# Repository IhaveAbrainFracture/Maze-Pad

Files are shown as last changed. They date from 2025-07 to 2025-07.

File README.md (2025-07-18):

# Maze-Pad made by @TheVirtuoso on slack, Vikas IRL
A general spin on a macro-pad, with a fully customised case, PCB, and Firmware. It should also be fully assemblable and useable less than 20 mins after getting everything. Big thanks to Hack Club (Highway) and PCBway for helping me make this





Here is the full cad model to view before you download anything or want a deeper look
https://cad.onshape.com/documents/6287fe38e10122eb28751222/w/de1210ab97eae6cc3d55f10b/e/6d662cd5a03a31552cd37cf9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

# sob story/ why im making this
im a broke highschool student while simultaniously being the youngest in my family often what this mean is all  (if not most) of the technology i own is either a hand-me-down, something i bought myself or something i 'borrowed without the intention of returning' to prove this point want to guess what my current keyboard and mouse look like? Wrong its one of those chunky school keyboard and mice combos that your school bulk buys for there comp room. aside i rly needed an upgrade so i decide to stop being a lazy and work on something. further down the line i also plan on making a keyboard so i kind of treated this as a 'test' run so i could learn the ropes and all

# Specification /cool gimicks (software)
- fully custom code (ie i didnt just yoink the hackpad guide code and make some tweaks)
- 4 macros ( Copy,Paste,Save and alt tab)
- 2 light control buttons ( change in colour, change in pattern)
- 1 layer (I plan on making this 2 layer or more in the future)

 # Specification /cool gimicks (Electronics)
  - wired in a 2x3 matrix
  - custom pcb with funni silk image
  - 2 leds (Neo pixels) which are poorly spaced apart
  - Hopefully smd mounted Xiao
  - diodes at the back
  - 

# Specification /cool gimicks (Mechanical)
- fully custom case which doesnt require screws, Bolts or glue (i designed the case based on cool woodworking stuff)
- 7 fully custom mazes for your ADHD
- Custom Maze themed keycaps



- Groves on the side
- maximum fillets
- high mounted cover (this is on purpose i swear, its so it fits my stuff)
- crude hole to look over your enslaved xiao
- backlighting
- funni logos and names
- its black, and white
 

# instruction to build
ngl if ur building this ur either chonicaly lazy or are collecting hackpads liek infinity stones cos like it cannot be that hard to build your ow. *Aside*
1. plug in your xiao and hold the boot button (clickty clackity on the right) then move the entire firmware folder into the xiao
2. assemble the easy stuff ie the keycaps and put them of the switches
3. place the pcb and all soldered part attacked to it into the main bases (the chunky 3D print)
5. in the allocated slot add the side connector thing thats white and the other white part, for the small bridge if u want the random logoing i put use that side if not rotate it 180 and place it
6. place the case lid and test
7. place small bearing balls into all the mazes
8. done

# bill of mats

| Item | Ammount |From where|
| --- | --- |---|
|  mx switches x6  |  |from hackpad kit (i need one of the kits btw)|
|Seeed XIAO RP2040 x1 ||("")|
|SK6812 MINI-E LEDs x2 ||("")|
|3D Printing| none|Printing legion|
|PCB|??$|PCBWAY, Im getting sponsered :D < |
|Solder Iron|??|???|
|Flux|$1.53|"https://www.aliexpress.com/item/1005008783332875.html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"order"%3A"231"%2C"eval"%3A"1"%7D&pdp_npi=4%40dis%21AUD%217.41%211.53%21%21%2134.52%217.16%21%40212e508d17522305550312149ef5c6%2112000046648707772%21sea%21AU%210%21ABX&curPageLogUid=8c35HYaTwcCc&utparam-url=scene%3Asearch%7Cquery_from%3A"|
|Solder|$1.53| https://www.aliexpress.com/item/1005007703287757.html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"order"%3A"3030"%2C"eval"%3A"1"%7D&pdp_npi=4%40dis%21AUD%216.45%211.53%21%21%2130.03%217.13%21%400b1bf20817522311015765496e776c%2112000041915671265%21sea%21AU%210%21ABX&curPageLogUid=g3sCp5CWQzIl&utparam-url=scene%3Asearch%7Cquery_from%3A|

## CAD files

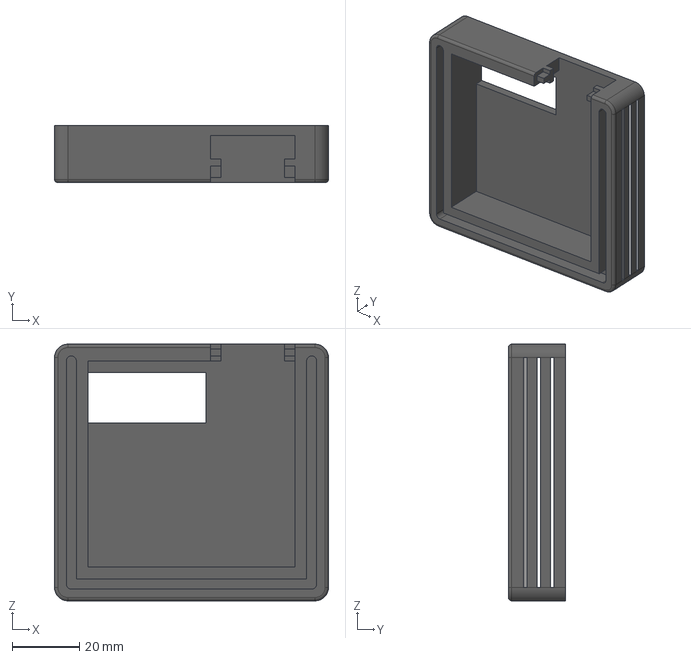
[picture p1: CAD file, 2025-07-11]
CASE FILES./All 3D printed stuff - Main base.step
81.4 x 17.0 x 76.2 mm

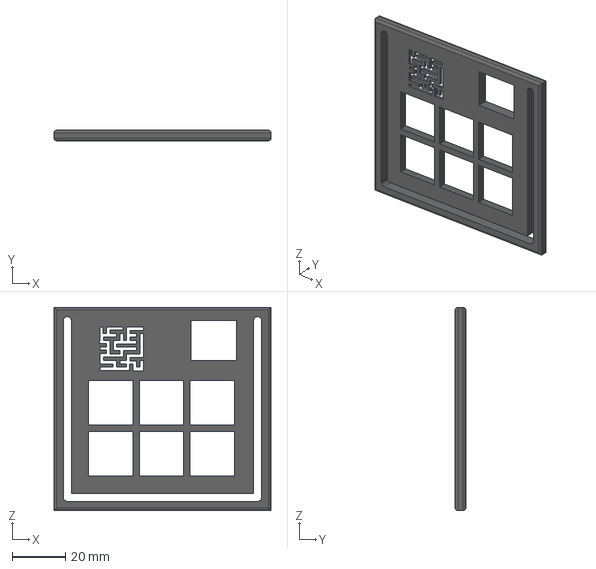
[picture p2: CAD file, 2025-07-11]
CASE FILES./All 3D printed stuff - Case.step
81.4 x 4.00 x 76.2 mm

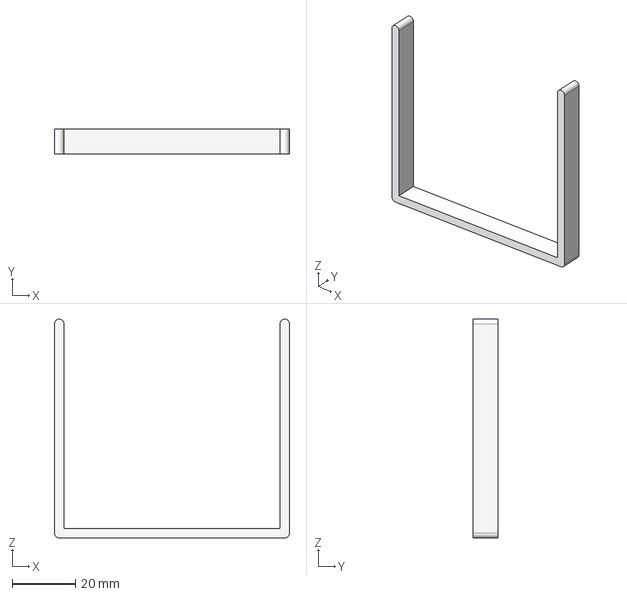
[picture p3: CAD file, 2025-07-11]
CASE FILES./All 3D printed stuff - Side Connecter.step
74.4 x 8.00 x 69.2 mm

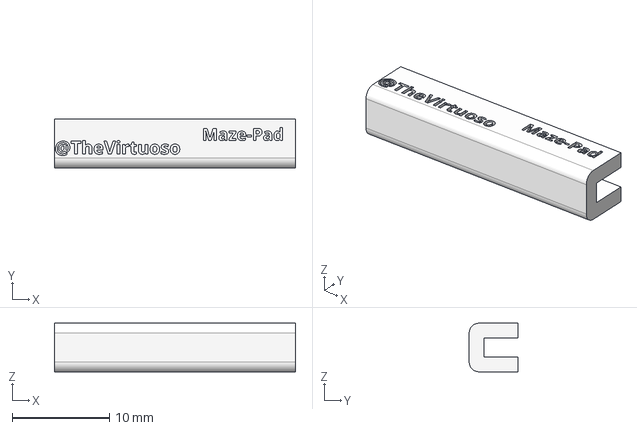
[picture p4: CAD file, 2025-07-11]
CASE FILES./All 3D printed stuff - Front Bridge.step
24.8 x 5.00 x 5.00 mm

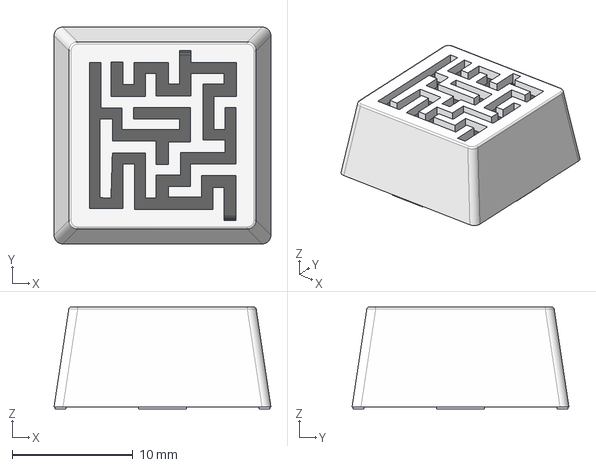
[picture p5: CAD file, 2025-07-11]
CASE FILES./Keycap.step
18.0 x 18.0 x 8.45 mm

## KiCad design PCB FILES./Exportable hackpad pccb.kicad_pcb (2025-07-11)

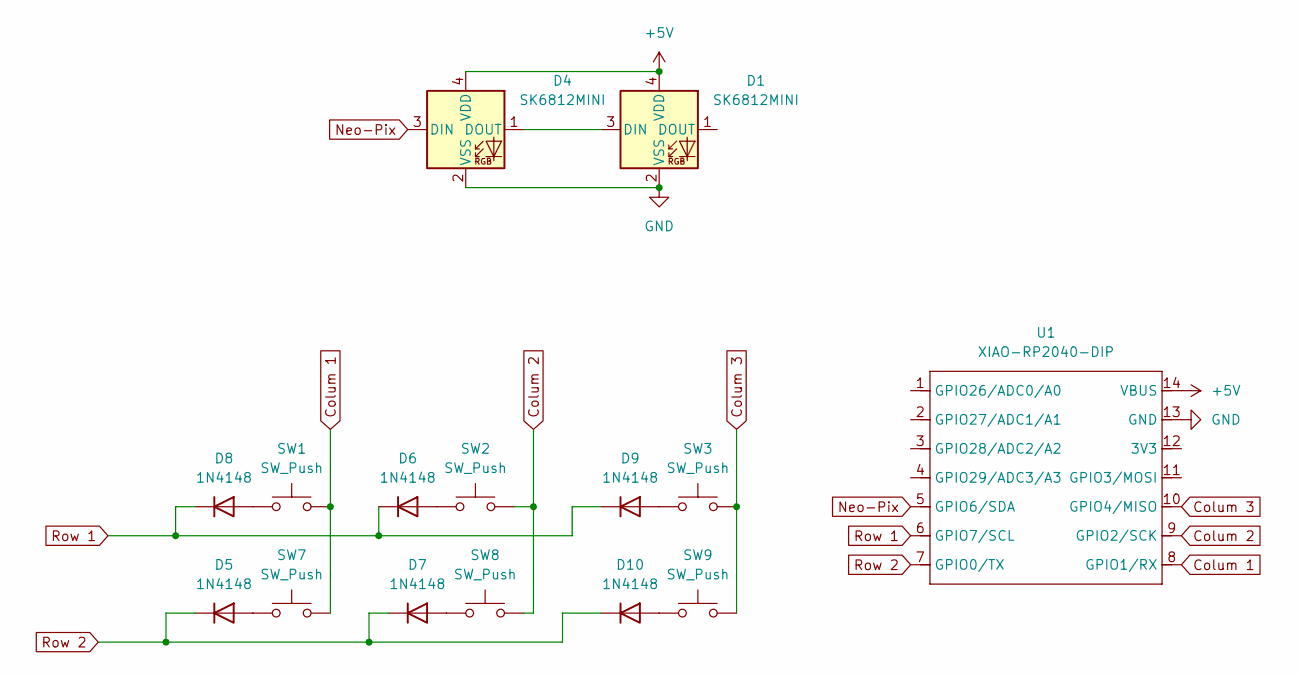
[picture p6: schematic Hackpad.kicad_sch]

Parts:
D1, D4: SK6812MINI; LED_SK6812MINI_PLCC4_3.5x3.5mm_P1.75mm
D5, D6, D7, D8, D9, D10: 1N4148; D_DO-35_SOD27_P7.62mm_Horizontal
SW1, SW2, SW3, SW7, SW8, SW9: SW_Push; SW_Cherry_MX_1.00u_PCB
U1: XIAO-RP2040-DIP

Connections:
+5V: D1.4 (VDD), D4.4 (VDD), U1.14 (VBUS)
Colum 1: SW1.2, SW7.2, U1.8 (GPIO1/RX)
Colum 2: SW2.2, SW8.2, U1.9 (GPIO2/SCK)
Colum 3: SW3.2, SW9.2, U1.10 (GPIO4/MISO)
GND: D1.2 (VSS), D4.2 (VSS), U1.13 (GND)
Neo-Pix: D4.3 (DIN), U1.5 (GPIO6/SDA)
unnamed: D1.3 (DIN), D4.1 (DOUT)
unnamed: D5.2 (A), SW7.1
unnamed: D6.2 (A), SW2.1
unnamed: D7.2 (A), SW8.1
unnamed: D8.2 (A), SW1.1
unnamed: D9.2 (A), SW3.1
unnamed: D10.2 (A), SW9.1
Row 1: D6.1 (K), D8.1 (K), D9.1 (K), U1.6 (GPIO7/SCL)
Row 2: D5.1 (K), D7.1 (K), D10.1 (K), U1.7 (GPIO0/TX)

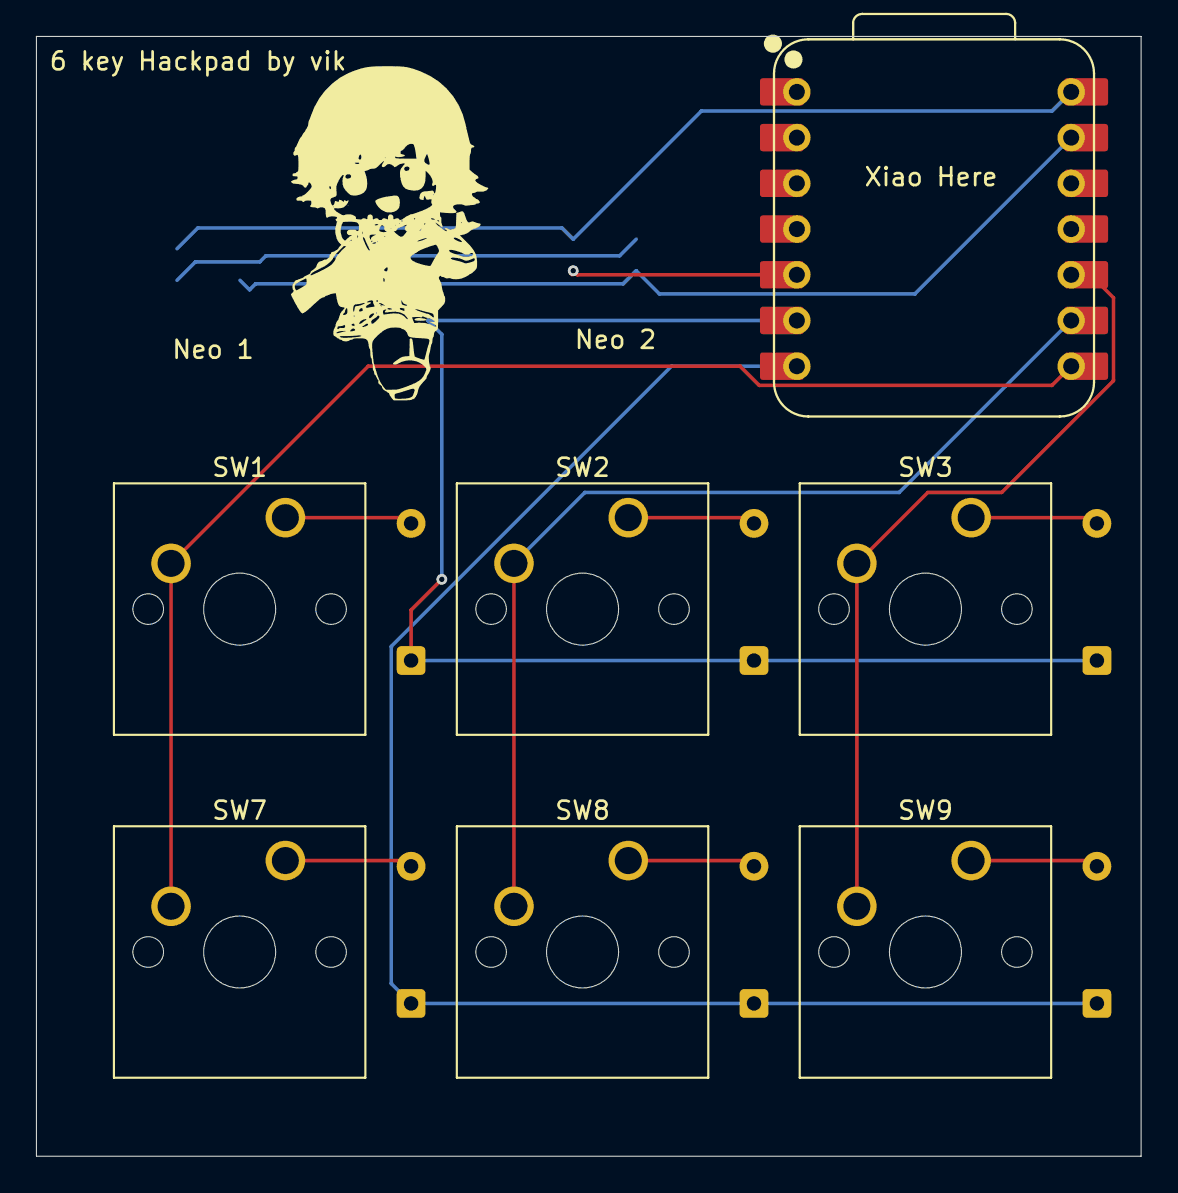
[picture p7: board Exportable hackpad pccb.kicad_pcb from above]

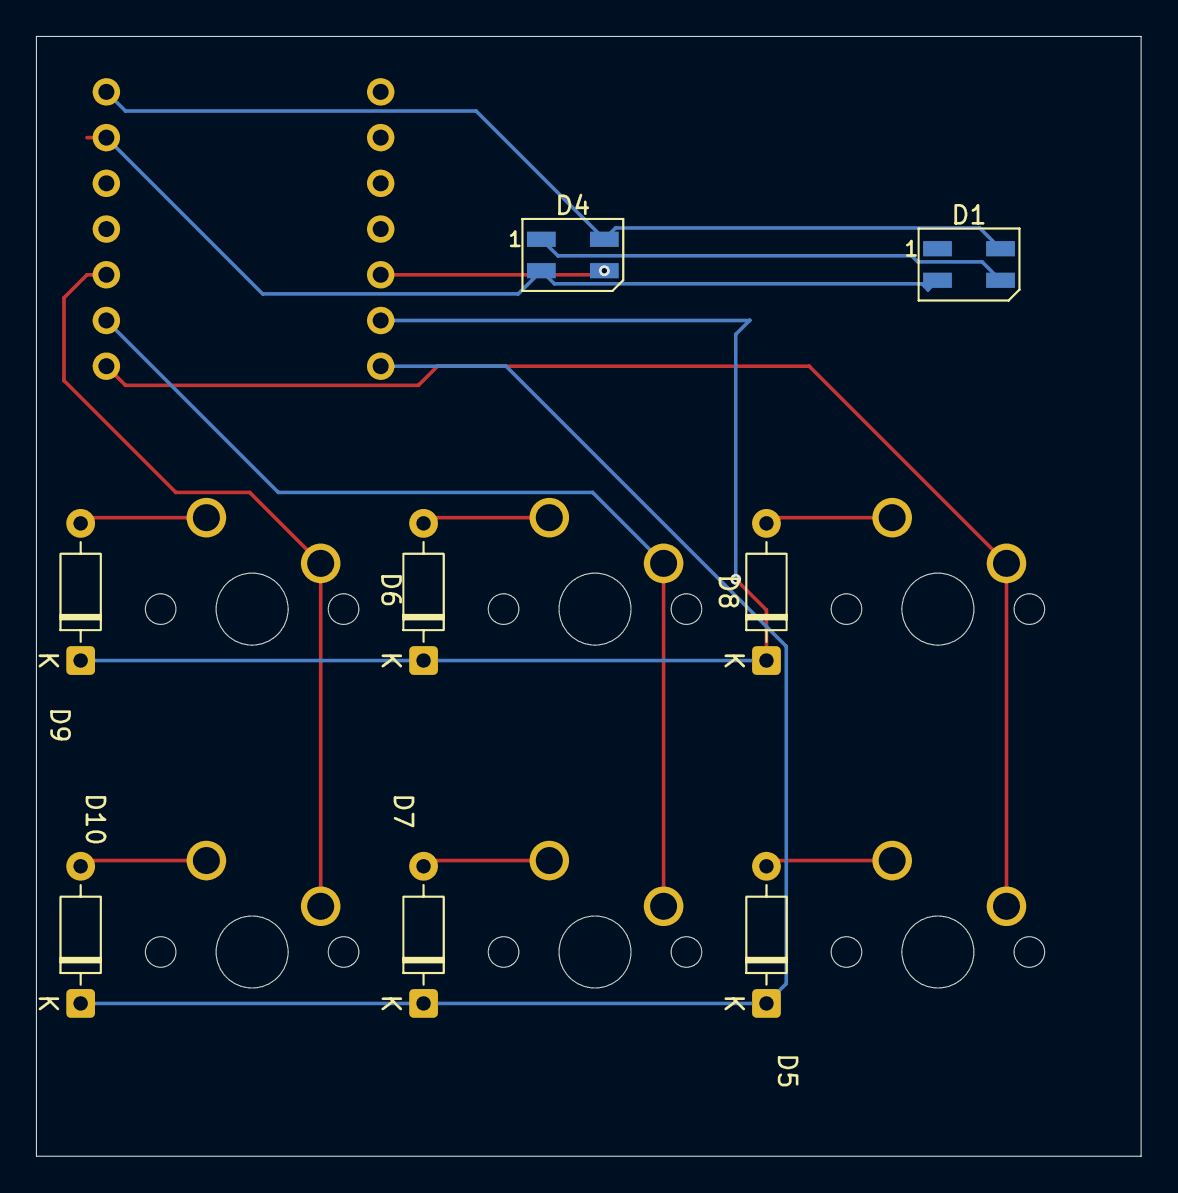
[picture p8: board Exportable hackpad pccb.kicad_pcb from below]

Board: 2 copper layers, 61.4 x 62.2 mm, 15 parts (8 on the bottom side), 15 nets.

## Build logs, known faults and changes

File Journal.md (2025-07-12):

---
title: "Maze-Pad"
author: "TheVirtuoso (me)"
description: "A maze themed hackpad/macropad"
created_at: "09/07/25"
---

just a brief heads up that i did not journal in real time for this meaning thatwriting everything in past tense/ from memory

Total hours ~17

# 9/07/25 ~5h hours 
the plan is to work on electronics. already had a look at the hackpad guide  and had a long discussion with taran(hackpad nerd) and he suggested i start with a pcb so thats what im doing. also as a note it was rly cool to learn how to finnaly make pcbs

so this was my first attempt at a matrix and i mean its obvious to me now how cooked it was but again learning exp on that note here is my 2nd attempt after bothering taran

then finnaly after watching like 3 yt videos and stuff i got this it should also be noted that i cut down on the amount of neo pixels cos yes 


so like making the schematics should be the easy part right? WRONG IM STUPID. in short i took 3 attempt at wiring my stuff here are the attempts





and guess the funny thing the text i added was in edge cut and i had no clue untill 2h later so im here panicking and stressing and all i had to do was click clack either way the final pcb and schematics look like this




# 10/07/25 ~8h
i think i finished pcb and just collapsed cos i was sendign msgs at 2 am and then poof so ye. either way im quite confident in my cad skills so i expected this to not make long. damn i was wrong im gonna pop some picture here and then explain stuff









aight time to explain, so the first image is the major sketch which provides extrudes for the case lid,base and side connector. more or less this is the big thing that everythign is based on. the following images are of me importing the pcb,switches and xiaos while assemblying them, as a note in onshape u have a area to make parts and a area to assemble parts so if you import a pcb with a xiao on it guess what you gotta make that xiao then mate it to the pcb its like being given a bag of legos without instructions. ik a few of the photos are of the mazes and that works by either importing an image and then tracing it like on the case or full sending and messing around like on the keycaps. another fun note is that i accidently CADed the entire thing upside down :< oh ye and the 3rd last picture is the original colour plan but as you may figure out it look a little to close to the nazi germany flag so i changed it

# 11/07/25 ~4H
no photos here i just did software and github stuff i will note software stuff was not fun but the online kmk stuff is great so it wasnt too much of a pain

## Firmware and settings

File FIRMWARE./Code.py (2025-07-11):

print("Starting")

import board

from kmk.kmk_keyboard import KMKKeyboard
from kmk.keys import KC, Keyboard
from kmk.scanners import DiodeOrientation
from kmk.modules.macros import Macros
from kmk.modules.macros import Press, Release, Tap
from kmk.extensions.rgb import RGB


keyboard = KMKKeyboard()
macros = Macros()
keyboard.modules.append(macros)
keyboard.col_pins = (board.GP1, board.GP2, board.GP4)
keyboard.row_pins = (board.GP0, board.GP7)
keyboard.diode_orientation = DiodeOrientation.COL2ROW


PASTE =KC.MACRO(
  (
    KC.LCTL(KC.V)),
  )

COPY =KC.MACRO(
  (
    KC.LCTL(KC.C)),
  )


Save =KC.MACRO(
  (
    KC.LCTL(KC.S)),
  )

Alt_Tab =KC.MACRO(
  (
    KC.LALT(KC.LTAB),
  )
)

rgb = RGB(pixel_pin=board.GP6, num_pixels=2)
keyboard.extensions.append(rgb)



keyboard.keymap =     [
        KC.RGB_MODE_BREATHE,    KC.RGB_VAI,    Alt_Tab,
        COPY,                   PASTE,         Save,
    ],


if __name__ == '__main__':
    keyboard.go()

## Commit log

2025-07-11 manufacturing files
    all the files you would need to manufacture the pcb
    [Exportable hackpad pccb-B_Cu.gbr, Exportable hackpad pccb-B_Mask.gbr, Exportable hackpad pccb-B_Paste.gbr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]
2025-07-11 Pcb stuff from kicad
    [Exportable hackpad pccb.kicad_pcb, Hackpad.kicad_sch]
2025-07-11 All the 3d prints in STEP
    All of the 3d prints you need to print out, just a note remember to print 6 keycaps
    [All 3D printed stuff - Case.step, All 3D printed stuff - Front Bridge.step, All 3D printed stuff - Main base.step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]
2025-07-16 files organised
    [All 3D printed stuff - Case.step, All 3D printed stuff - Front Bridge.step, All 3D printed stuff - Main base.step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]
2025-07-18 Update README.md for hq and pcbway
